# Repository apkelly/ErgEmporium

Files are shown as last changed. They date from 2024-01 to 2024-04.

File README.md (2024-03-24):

# Concept 2 Rower Experiments, hacks and upgrades

The projects below are my experiments and upgrades to my personal Concept 2 Rower, if you want to perform these same upgrades
you'll need access to a 3D printer and some basic tools such as a screwdriver or an adjustable wrench to remove some of the 
bolts on the rower.

all prints - green

Unless noted, all these sub-projects are non-destructive to your Concept 2 Rower, any installation if done carefully can be reversed
and you rower returned to its original factory condition.

Where additional parts are needed I'll aim to include sizes and costs etc.

1. [VESA mount for computer monitor v1](/vesa%20mount%20v1)
1. [PM5 low mount v1](/pm5%20low%20mount%20v1)
1. [Chain Lubricator Tool v1](/chain%20lube%20tool%20v1)
1. [PM5 low mount v2](/pm5%20low%20mount%20v2)

# Risk
I've made every attempt to make sure these components are strong, safe, reversible etc. I provide no warranty though, if you decide to attempt to install these you do so at your own risk.
I won't be held liable for any breakages, scratches or damage to your Concept 2 rower, PM5 monitor, your computer monitor/TV, or yourself from following these instructions. 

I wish you well, and I hope you find these enhancements useful, I've tested everything on my own personal Concept 2 Model D rower. If you're not comfortable taking apart electronics, or using an adjustable wrench and screwdriver, then please ask for assistance or reconsider your usage of these files.

# Community
You're free to use the files in this repository for personal use, if you make changes or improvements that you think would benefit the community please
let me know and I can upload the improved versions here (or link to your repository if you prefer).

If you do use these files please do share your results with the community (and me), I'd love to see these being used and enjoyed by everyone.

# License
You're free to use the files in this repository for personal use, commercial use is prohibited.

https://creativecommons.org/licenses/by-nc/4.0/legalcode.en

# ErgEmprorium Etsy store
If you don't have access to a 3D printer but would like to install these enhancements on your own Concept 2 Rower, please check out my [Etsy store](https://ergemporium.etsy.com) where I sell and ship pre-printed versions.

If you do have a 3D printer and would still like to support my open source efforts, there is a digital "Thank you" card you can purchase on my store which directly goes to helping me work on projects like these.

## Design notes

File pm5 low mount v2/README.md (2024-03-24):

# PM5 mount low mount v2

This project moves the PM5 monitor to a lower position on the Concept 2 rower, a perfect companion to the VESA monitor mount, allowing you to still see your stats while enjoing your favourite Netflix or Disney+ shows.

## Installation

### Step 1 -  the PM5 monitor.

The battery cover on the PM5 is held in place with a single screw.

Remove this screw and pull away the battery cover, keep this in a safe place.

Use the new battery cover with in-built sliding joint, it affixes to the back of the PM5 replacing the battery cover you just removed, and reuses the battery screw supplied with the PM5.

### Step 2 - the PM5 monitor mount.

The monitor mount is secured to the side of the main vertical shaft, that previously held the PM5 monitor arm.

With your Concept 2 rower you should have received a screwdriver for assembly, use this screwdriver to remove the 2 upper screws on the shaft (on the opposire side to the flywheel)

Insert the nuts from these 2 screws into the side holes on the monitor mount, we're going to re-insert these screws back into their original holes, but backwards, screwing from the inside outwards.

Once the monitor mount is secured to the side of your rower, the PM5 monitor with new battery cover should slide into the groove running down the length of the mount (note: initially this may be stiff, this is on purpose, start slowly and use a method where you insert and remove the mount multiple times, going deeper each time).

Once the PM5 is secured to the side of your rower you can re-attach the sensor cable.

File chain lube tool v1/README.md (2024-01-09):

# Chain lubricator tool v1

This tool is useful when it comes time to lubricate your Concept 2 rowser chain. 

If you attempt this solo it can be tricky to hold the chain while applying the lubricating oil. This tool hooks over the end of the rower and will hold the chain handle securly in place while to apply the oil, allowing you to perform this operation single-handidly.

Simply slip the 2 feet around the rear of the rower, above the rear feet, then slip the silver U shaped bold in the handle over the tool's handle.

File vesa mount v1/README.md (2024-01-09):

# VESA mount for computer monitor v1

This project replaces the PM5 mounting arm with an arm that allows you to mount a computer monitor (or small TV) using a standard 75x75mm or 100x100mm VESA mount.
With this replacement you can then use any input source your monitor/TV supports e.g. Chromecast via HDMI, to watch the content you want
while doing your workout.

I've tested this arm with a 24" LG monitor (pictured) and it supports the weight without issue. A larger monitor may need a longer arm to clear the 
Concept 2 rowing chain, and possibly may also need increased strength. If you're attempting to use a larger monitor please let me know.

Note, that with this project the PM5 is removed completly. It can still be attached to the sensor wire, but if won't be supported in any way. See the
PM5 low mount project for a mounting solution that lets you continue to use the PM5 with the VESA mounted monitor.

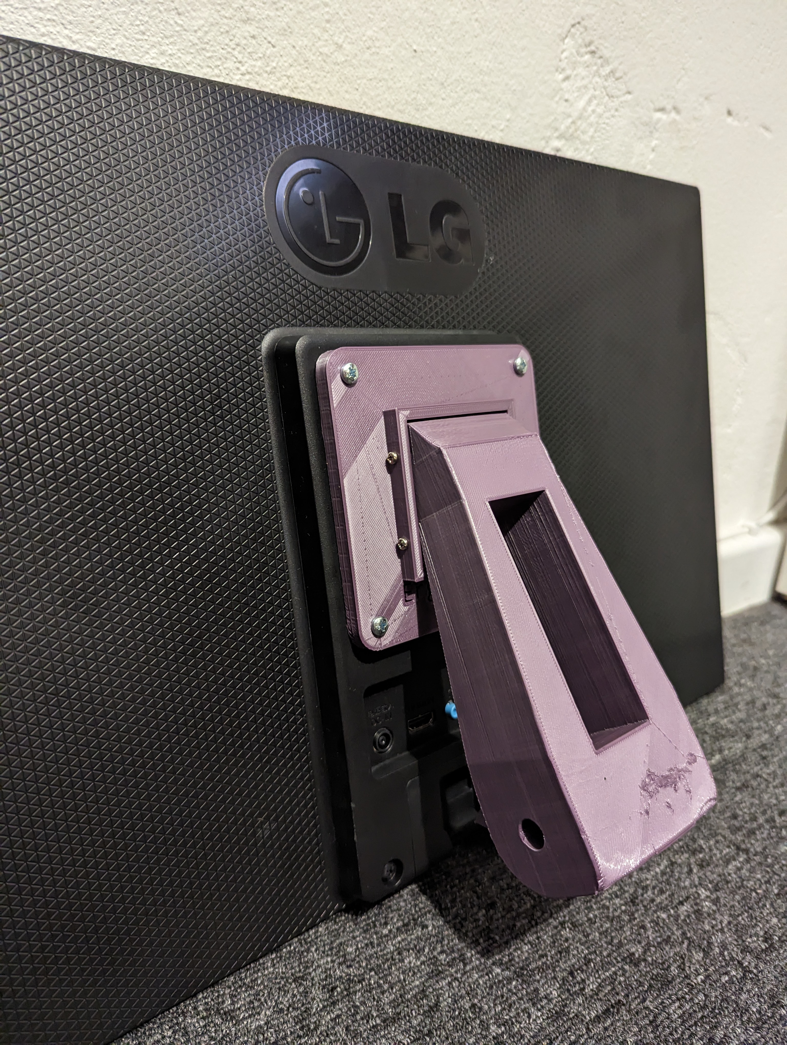
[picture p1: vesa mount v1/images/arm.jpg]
VESA mount and monitor arm


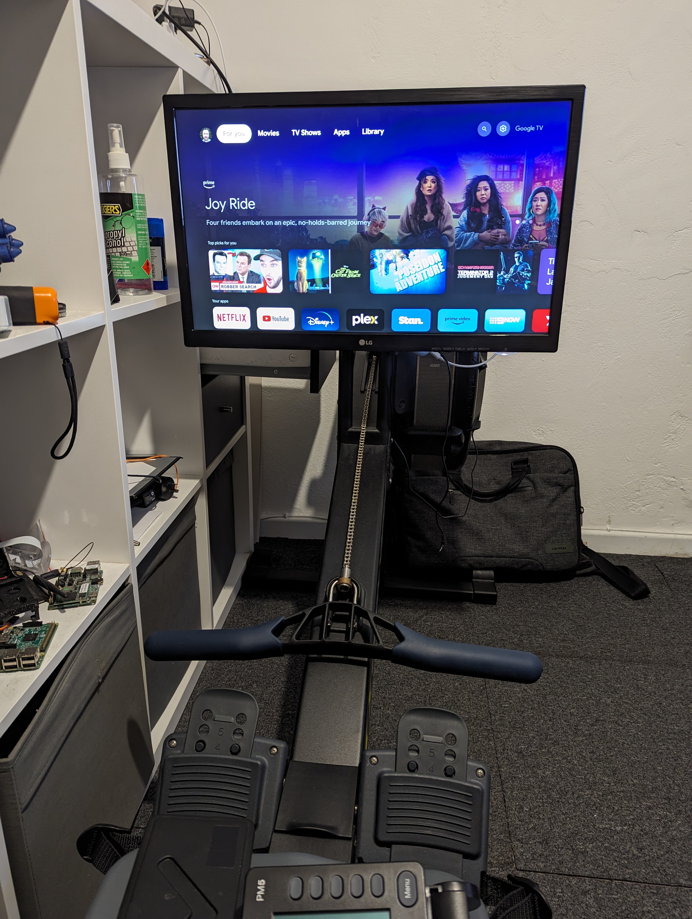
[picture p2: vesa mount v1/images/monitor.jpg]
24" LG monitor in use


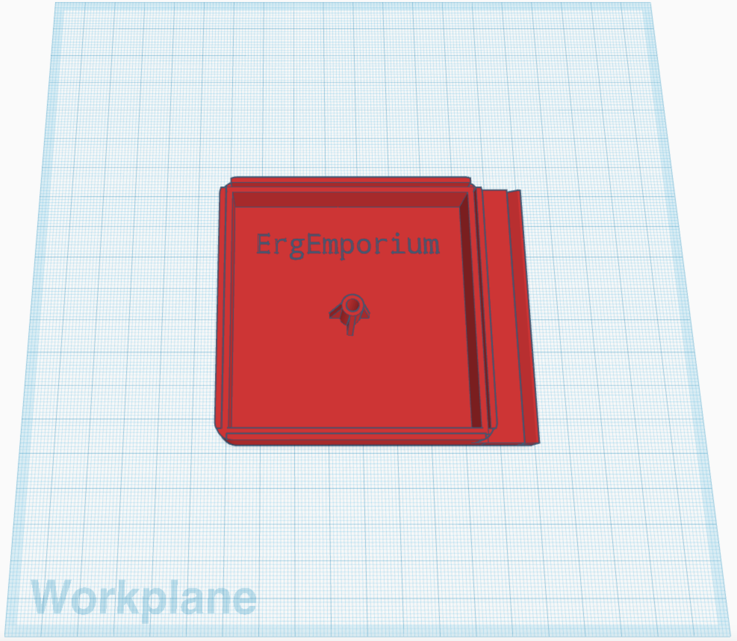
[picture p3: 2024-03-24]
pm5 low mount v2/images/tinkercard-pm5-battery-cover.png

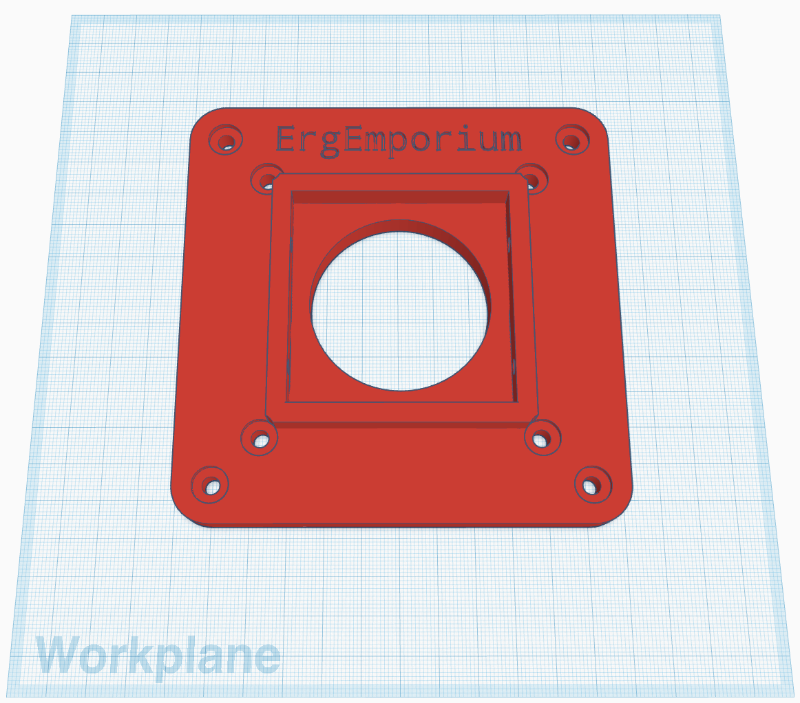
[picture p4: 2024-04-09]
vesa mount v1/images/tinkercad-vesa-mount.png

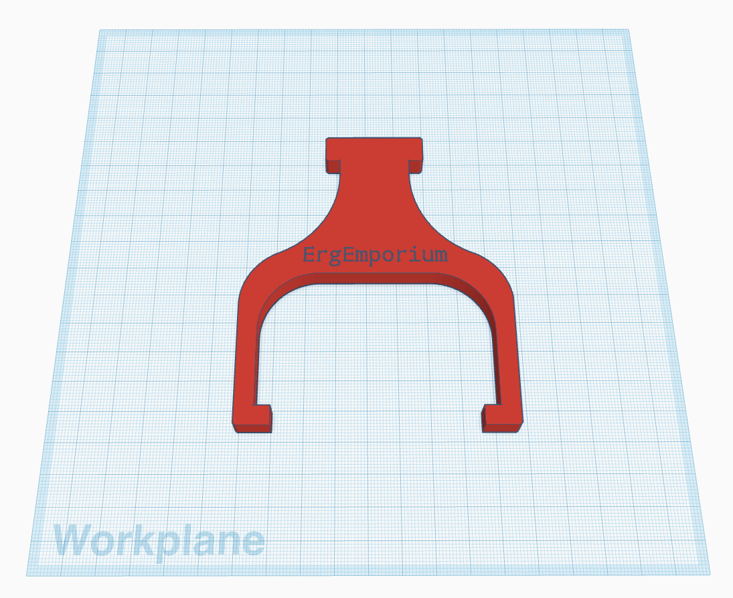
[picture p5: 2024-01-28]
chain lube tool v1/images/tinkercad-chain-lubricator-tool.png

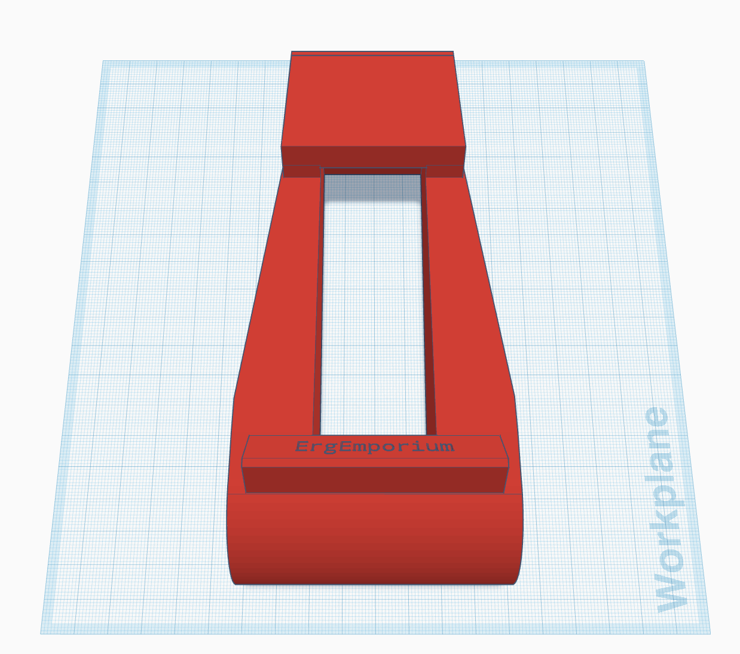
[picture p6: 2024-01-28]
vesa mount v1/images/tinkercad-vesa-arm.png

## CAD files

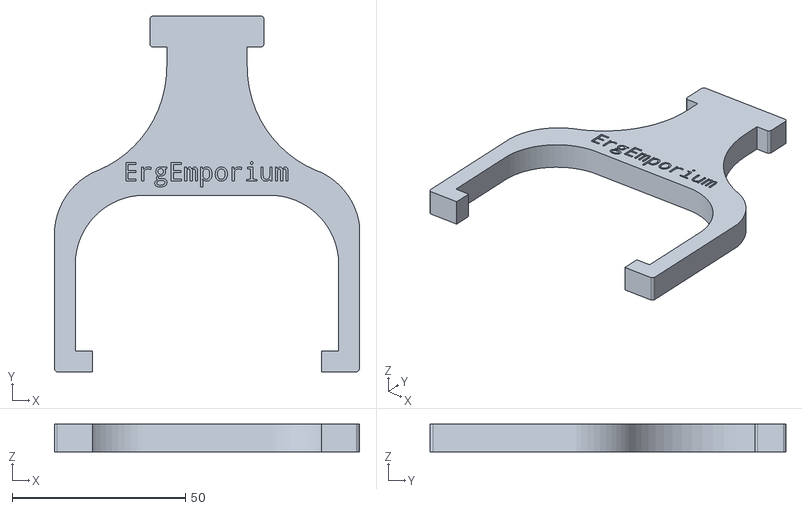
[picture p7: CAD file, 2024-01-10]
chain lube tool v1/chain-lubricator-tool.stl
88.0 x 102.7 x 8.00

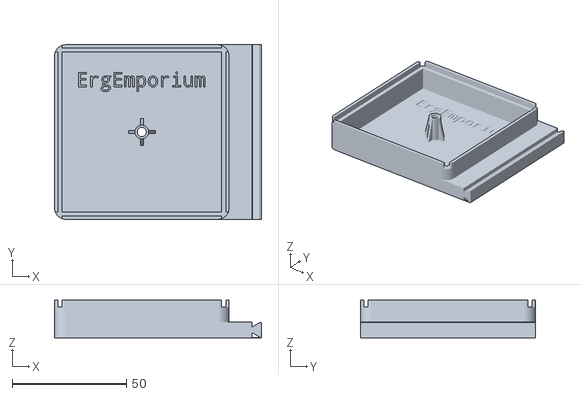
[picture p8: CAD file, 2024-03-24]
pm5 low mount v2/pm5-battery-cover.stl
90.7 x 76.5 x 16.5

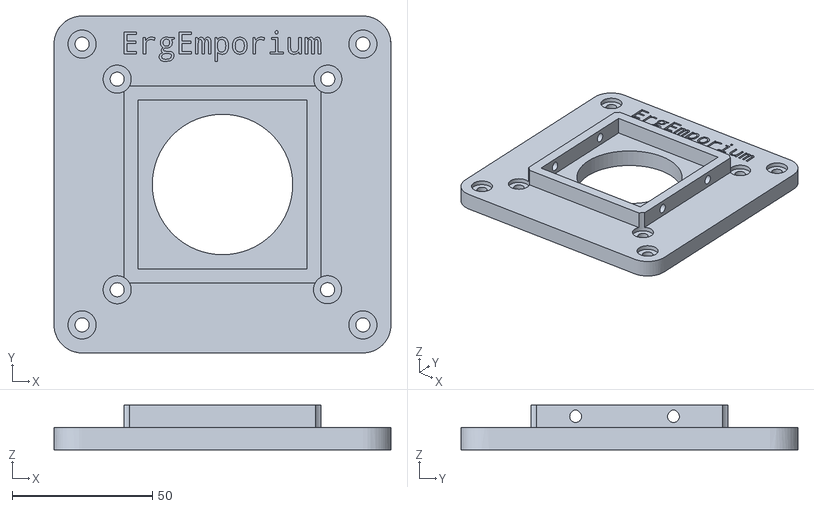
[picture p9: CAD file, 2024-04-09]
vesa mount v1/vesa-mount.stl
120.0 x 120.0 x 16.0

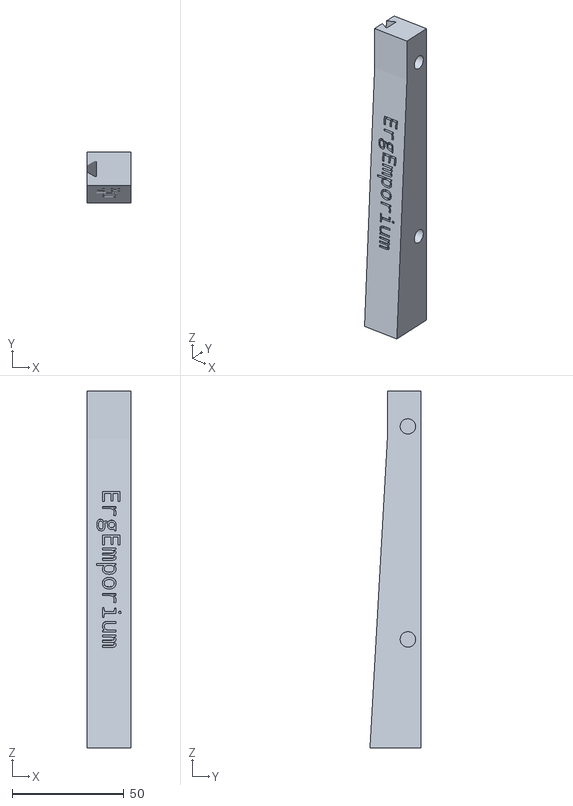
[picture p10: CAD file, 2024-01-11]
pm5 low mount v2/pm5-mount.stl
19.5 x 22.9 x 160.0

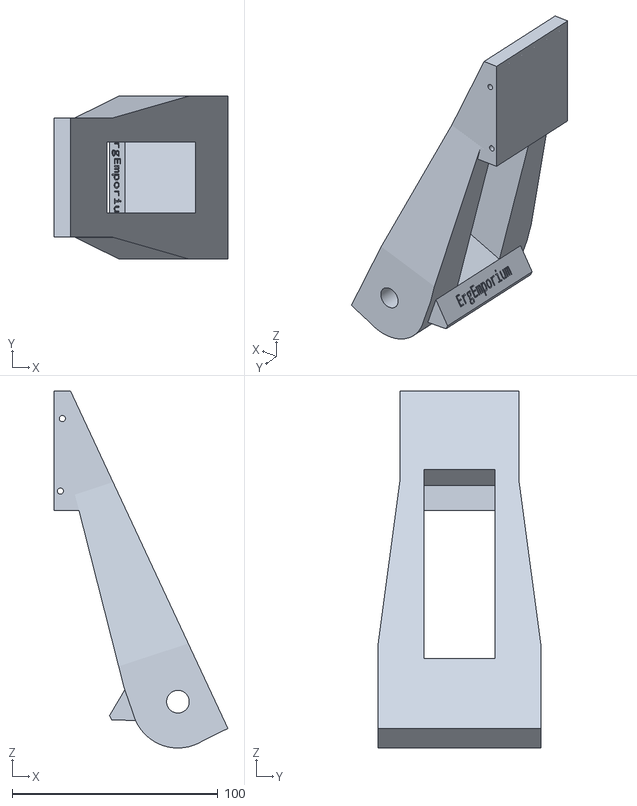
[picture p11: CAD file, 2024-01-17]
vesa mount v1/vesa-arm.stl
84.4 x 79.0 x 173.3

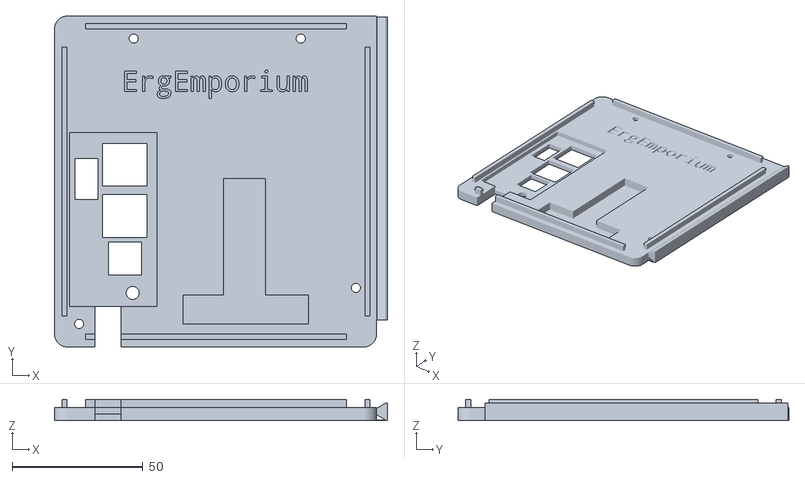
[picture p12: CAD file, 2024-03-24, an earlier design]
pm5 low mount v1/pm5-rear-cover.stl
127.6 x 126.8 x 8.20

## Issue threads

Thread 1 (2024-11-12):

changes on RowErg

sspeed22, 2024-11-12:
Hi, don't know if this is where you want these issues.  I received the kit today, awesome little invention.  Looks like there were some changes to the RowErg.

1) Cable now runs in the arm.  Just need to take a screw out to get that apart.

2) The two screws for the PM5 mount are now very short and the nut is flanged so they don't fit into the holes.  I dremeled them out (hope I didn't wreck it), but didn't matter because the screws are too short anyway.  Will go look for some longer screws.

apkelly, 2024-11-17:
Hey, thanks for your feedback, you can reach me here or on Etsy is you purchased a kit from there.

I'm going to look into supplying the correct length of screw and nut in the package to avoid the situation you describe, I've had several customers raise the same problem as you've experienced.

Thanks.

Closed 2024-11-17.

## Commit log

2024-01-01 Initial import of VESA mount arm.
    [concept-2-arm.stl, vesa-mount.stl]
2024-01-03 Include ErgEmporium branding into model.
    [concept-2-arm.stl, vesa-mount.stl]
2024-01-05 New PM5 mount files
    Update docs.
    [pm5-mount.stl, pm5-rear-cover.stl]
2024-01-05 Rename folders
    Update docs
    [pm5-mount.stl, pm5-rear-cover.stl]
2024-01-05 Strengthen rear plate, add hole for reset button.
    [pm5-rear-cover.stl]
2024-01-09 Add chain lubricator tool
    Add 75x75mm design for vesa mount
    [chain-lubricator-tool.stl, vesa-mount.stl]
2024-01-10 Smooth corners, shorten handle.
    [chain-lubricator-tool.stl]
2024-01-11 Remove glb files, STL files should be enough for everyone.
2024-01-11 Increase width slightly to avoid bolt holes and rail from touching.
    Move logo to the front.
    [pm5-mount.stl]
2024-01-14 Move reset hole to be in better position.
    [pm5-rear-cover.stl]
2024-01-17 Improve strength and reduce filament usage for VESA arm.
    [concept-2-arm.stl]
2024-01-28 Latest design for PM5 rear cover, includes cover around USB ports.
    Upload Tinkercad images
    Rename vesa arm filename
    [vesa-arm.stl]
2024-01-30 Refinements in tolerances.
    [pm5-rear-cover.stl]
2024-02-29 PM5 battery mount coming soon.
2024-03-24 Widen cut-out for motherboard capacitors.
    [pm5-rear-cover.stl]
2024-03-24 Battery mount for the PM5
    [pm5-battery-cover.stl, pm5-mount.stl]
2024-04-09 Add countersink holes to allow for short screw lengths
    Increase size of screw holes to allow fitting of an M3xL4xOD4.2 brass insert nut.
    [vesa-mount.stl]
2026-02-09 Add v2 of the VESA mount, update Etsy store link.
